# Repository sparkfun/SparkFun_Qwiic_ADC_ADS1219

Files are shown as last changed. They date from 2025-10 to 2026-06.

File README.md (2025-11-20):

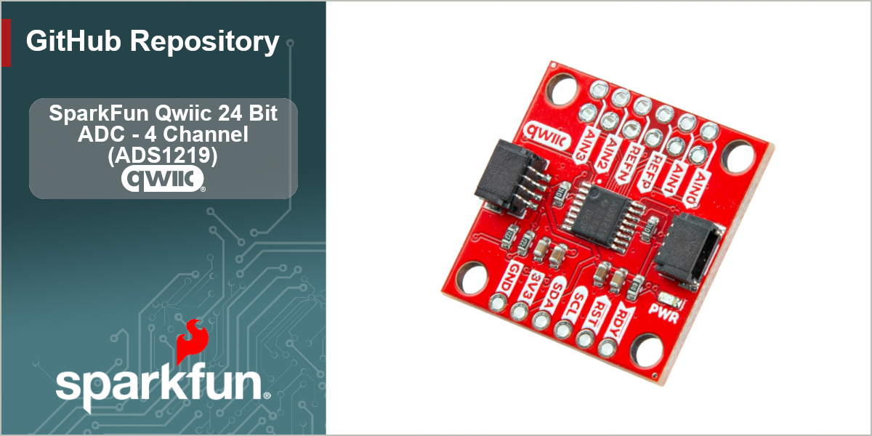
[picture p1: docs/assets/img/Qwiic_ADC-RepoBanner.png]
SparkFun Qwiic 24 Bit ADC - 4 Channel (ADS1219) (https://www.sparkfun.com/sparkfun-qwiic-24-bit-adc-4-channel-ads1219.html)


[*SparkFun Qwiic 24 Bit ADC - 4 Channel (ADS1219) (SEN-27544)*](https://www.sparkfun.com/sparkfun-qwiic-24-bit-adc-4-channel-ads1219.html)

A lot of the time you just need to add more analog inputs to solve a problem. It happens. The SparkFun Qwiic 24-Bit ADC can provide four channels of I2C controlled ADC input to your Qwiic enabled project. These channels can be used as single-ended inputs, or in pairs for differential inputs, running at sample rates of up to 1kHz. What makes this ADC even more powerful is that it has a programmable x1 or x4 gain amplifier that lets you "zoom in" on a very small change in analog voltage (but will still effect your input range and resolution). Utilizing our handy Qwiic system, it is easy to connect it to the rest of your system. However, we have broken out 0.1"-spaced pads too in case you prefer to use a breadboard. The analog inputs and reference pins are all broken out on 0.1"-spaced pads too. This board does not have screw terminals - there was not enough room!

The ADS1219 can use its own internal 2.048V voltage reference for measurements, or you can provide your own reference via the REFP and REFN breakout pads. You can also provide your own VDDA (AVDD) by opening the jumper and connecting a voltage to the VDDA pad. This ADC board has eight address jumpers that let you choose one of sixteen unique addresses (0x40 to 0x4F). With these, you can connect up to sixteen of these on the same I2C bus and have 64 channels of ADC. The maximum resolution of the converter is 24-bits, corresponding to 244.14nV per count at a gain of x1. At a gain of x4, the resolution is 61.04nV per count. Note: the effective resolution is limited to 20-bits.

Repository Contents
-------------------

* **/docs** - GitHub pages documentation files
* **/Documentation** - TI datasheet 
* **/Hardware** - KiCad design files (_pcb, _sch), Schematic (PDF)
* **/Production** - Production panel files (_pcb, gerbers)

Documentation
--------------
* [**Arduino Library**](https://github.com/sparkfun/SparkFun_ADS1219_Arduino_Library) - Arduino library for the ADS1219.
* [**Hookup Guide**](https://docs.sparkfun.com/SparkFun_Qwiic_ADC_ADS1219/)

Product Versions
-----------------

* [SPX-23455](https://www.sparkfun.com/sparkx-qwiic-24-bit-adc-4-channel-ads1219.html) - Original SparkX release.
* [SEN-27544](https://www.sparkfun.com/sparkfun-qwiic-24-bit-adc-4-channel-ads1219.html) - Initial SparkFun release.

License Information
-------------------

This product is _**open source**_! 

Please review the LICENSE.md file for license information. 

If you have any questions or concerns on licensing, please contact technical support on our [SparkFun forums](https://forum.sparkfun.com/viewforum.php?f=152).

Distributed as-is; no warranty is given.

- Your friends at SparkFun.

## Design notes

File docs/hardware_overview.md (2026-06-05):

Let's take closer look at the ADS1219 ADC and other hardware on this Qwiic breakout. Refer to the annotated image below as you read through.

<figure markdown>
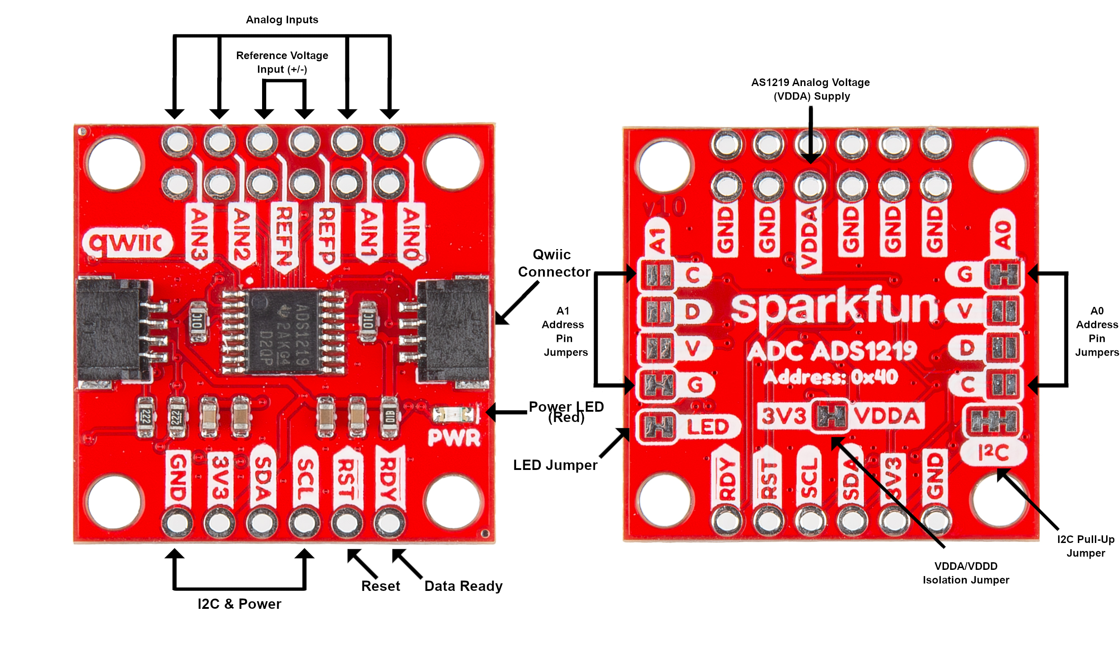
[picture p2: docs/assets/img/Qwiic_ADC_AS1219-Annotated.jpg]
Annotated photo of the Qwiic ADC - AS1219

</figure>

## ADS1219 Analog-to-Digital Converter

The ADS1219 is a high-precision, 24-bit analog-to-digital converter that communicates over I<sup>2</sup>C. It has two differential or four single-ended inputs managed by an internal input multiplexer, programmable gain settings of 1 or 4, rail-to-rail input buffers to allow connecting high-impedence devices directly to the ADS1219 and has 16 available I<sup>2</sup>C addresses so if you really need it, you can connect 16 of these to have up to 64 single-ended (or 32 differential) analog inputs on a single I<sup>2</sup>C bus! It also features an internal 2.048-V voltage reference and oscillator. Users can provide their own reference voltage throuh the REFN and REFP PTH pins on the board.

The ADS1219 has a supply voltage range of <b>2.3</b> to <b>5.5V</b>. The I<sup>2</sup>C address is configured via connecting the two address select pins (A0 and A1) to four pins on the ADS1219; Ground, DVDD, SDA and SCL. The board includes eight solder jumpers to set the ADS1219's address. Read on to the "Solder Jumpers" section on this page for information on adjusting the ADS1219's I<sup>2</sup>C address.

## Connectors

### Qwiic Connectors

As you'd expect, this breakout includes a pair of Qwiic connectors to easily integrate it into a Qwiic circuit. They connect to the ADS1219's I<sup>2</sup>C signals (SDA/SCL) and also power the ADC with <b>3.3V</b>.

### PTHs

The board breaks out all of the ADS1219's pins to three 0.1"-spaced PTH headers. On one side there is a 6-pin PTH header that routes the ADS1219's data and power pins including the I<sup>2</sup>C signals, reset and data ready pins. The other side of the board has a pair of 6-pin PTH headers. The outer header includes the ADS1219's four analog inputs as well as the positive and negative external reference voltage inputs. The inner header breaks out the ADS1219's analog voltage input (VDDA) along with five ground pins for the analog inputs and analog voltage input. Make sure to open the 3V3/VDDA solder jumper before connecting an external analog voltage input.

## LED

The sole LED on this board is a red power status LED to indicate when the board has power.

## Solder Jumpers

The board has eleven solder jumpers. The list below outlines the functionality of the three solder jumpers not related to setting the device's I<sup>2</sup>C address:

* <b>LED</b> - The LED jumper completes the red power LED circuit and is CLOSED by default. Open this jumper to disable the power LED.
* <b>I<sup>2</sup>C</b> - The I<sup>2</sup>C jumper pulls the SDA and SCL signals to <b>3.3V</b> through a pair of <b>2.2K&ohm;</b> resistors. Open the three-way jumper completely to remove the pull-ups from the bus if needed.
* <b>3V3-VDDA</b>  - The 3V3-VDDA jumper nets the ADS1219's digital and analog supply voltages together to both operate at <b>3.3V</b> and is CLOSED by default. Open this jumper to isolate the two voltages if you're supplying separate voltages for the analog and digital supplies.
 
The other eight jumpers control the ADS1219's I<sup>2</sup>C address and are grouped into labels <b>A1</b> and <b>A0</b>. Each group has solder jumpers labeled <b>G</b> (Ground), <b>V</b> (3.3V), <b>D</b> (SDA) and <b>C</b> (SCL). By default, the board connects both A1 and A0 to Ground and sets the address to <b>0x40</b>. The table below outlines all available configurations and the resulting addresses.

<table>
    <tr>
        <th>A1</th>
        <th>A0</th>
        <th>Address (Unshifted)</th>
    </tr>
        <td>G (GND)</td>
        <td>G (GND)</td>
        <td>0x40 (Default)</td>
    </tr>
    <tr>
        <td>G (GND)</td>
        <td>V (3.3V)</td>
        <td>0x41</td>
    </tr>
    <tr>
        <td>G (GND)</td>
        <td>D (SDA)</td>
        <td>0x42</td>
    </tr>
    <tr>
        <td>G (GND)</td>
        <td>C (SCL)</td>
        <td>0x43</td>
    </tr>
    <tr>
        <td>V (3.3V)</td>
        <td>G (GND)</td>
        <td>0x44</td>
    </tr>
    <tr>
        <td>V (3.3V)</td>
        <td>V (3.3V)</td>
        <td>0x45</td>
    </tr>
    <tr>
        <td>V (3.3V)</td>
        <td>D (SDA)</td>
        <td>0x46</td>
    </tr>
    <tr>
        <td>V (3.3V)</td>
        <td>C (SCL)</td>
        <td>0x47</td>
    </tr>
    <tr>
        <td>D (SDA)</td>
        <td>G (GND)</td>
        <td>0x48</td>
    </tr>
    <tr>
        <td>D (SDA)</td>
        <td>V (3.3V)</td>
        <td>0x49</td>
    </tr>
    <tr>
        <td>D (SDA)</td>
        <td>D (SDA)</td>
        <td>0x4A</td>
    </tr>
    <tr>
        <td>D (SDA)</td>
        <td>C (SCL)</td>
        <td>0x4B</td>
    </tr>
    <tr>
        <td>C (SCL)</td>
        <td>G (GND)</td>
        <td>0x4C</td>
    </tr>
    <tr>
        <td>C (SCL)</td>
        <td>V (3.3V)</td>
        <td>0x4D</td>
    </tr>
    <tr>
        <td>C (SCL)</td>
        <td>D (SDA)</td>
        <td>0x4E</td>
    </tr>
    <tr>
        <td>C (SCL)</td>
        <td>C (SCL)</td>
        <td>0x4F</td>
    </tr>
</table>

## Board Dimensions

The Qwiic ADC - ADS1219 is a standard 1"x1" Qwiic breakout with four mounting holes that fit a 4-40 screw.

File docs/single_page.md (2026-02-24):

---
hide:
  - navigation
  - toc
icon: fontawesome/solid/scroll
---

# Introduction
--8<-- "./docs/introduction.md"

# Quickstart Guide
--8<-- "./docs/quick_start.md"

# Hardware Overview
--8<-- "./docs/hardware_overview.md"

# Hardware Hookup
--8<-- "./docs/hardware_assembly.md"

# Arduino Setup
--8<-- "./docs/arduino_setup.md"

# Arduino Examples
--8<-- "./docs/arduino_examples.md"

# Troubleshooting
--8<-- "./docs/troubleshooting.md"

# Resources
--8<-- "./docs/resources.md"

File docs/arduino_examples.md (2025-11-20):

Let's take a look at a few of the examples included in the SparkFun ADS1219 Arduino Library.

## Example 01 - Single Shot

The first example shows how to take single-shot measurements of a differential input on channels A0 and A1. Open the example by navigating to **File** > **Examples** > **SparkFun ADS1219 Arduino Library** > **Example01_SingleShot**. Select your Board and Port and click the Upload button. After the code finishes uploading, open the [serial monitor](https://docs.arduino.cc/software/ide-v2/tutorials/ide-v2-serial-monitor/) with the baud set to **115200** and you should see some setup messages print out followed by readings in millivolts.

The example initializes the ADS1219 on the I<sup>2</sup>C bus with default settings and then attempts to take single-shot readings from the ADC. 

## Example 02 - Continuous

The second example shows how to take continuous measurements of a differential input on channels A0 and A1. This example is very similar to the previous one but instead of requesting for a single-shot synched readings, requests continuous readings every 10ms. Open the example from the SparkFun ADS1219 Arduino Library and upload it.

With the serial monitor open and set to **115200**, you should see an initialization message print followed by differential voltage readings from A0 and A1 in millivolts.

## Example 03 - Input Multiplexer

The third example shows how to configure the ADS1219's input multiplexer feature. This adjustable setting lets users set the ADS1219's input multiplexer to one of eight options using the `myADC.setInputMultiplexer();` function. Available settings are:

``` c++
  ADS1219_CONFIG_MUX_DIFF_P0_N1 //(Default)
  ADS1219_CONFIG_MUX_DIFF_P2_N3
  ADS1219_CONFIG_MUX_DIFF_P1_N2
  ADS1219_CONFIG_MUX_SINGLE_0
  ADS1219_CONFIG_MUX_SINGLE_1
  ADS1219_CONFIG_MUX_SINGLE_2
  ADS1219_CONFIG_MUX_SINGLE_3
  ADS1219_CONFIG_MUX_SHORTED
```

## Example 04 - Data Ready Interrupt

The fourth example demonstrates how to use the ADS1219's data ready pin to trigger an interrupt on a connected microcontroller. For this example, you'll need to connect the Data Ready (DRDY) pin to an [interrupt-capable I/O pin](https://docs.arduino.cc/language-reference/en/functions/external-interrupts/attachInterrupt/) on your development board. 

The code defaults to use D4 for the interrupt pin so if you need to switch to another pin, adjust this line:

``` c++
const int interruptPin = 4;
```

The example's setup sets the I<sup>2</sup>C clock speed to 400kHz for better performance and initializes the ADS1219 to read the voltage between AIN0 and Ground, adjusts the gain to x4 and configure the data rate to 1000 samples per second. Lastly, it configures the interrupt to go LOW when data is ready. The main loop just checks to see if the interrupt is seen, clears the flag and then prints readings in millivolts.

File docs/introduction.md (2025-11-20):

<figure markdown>
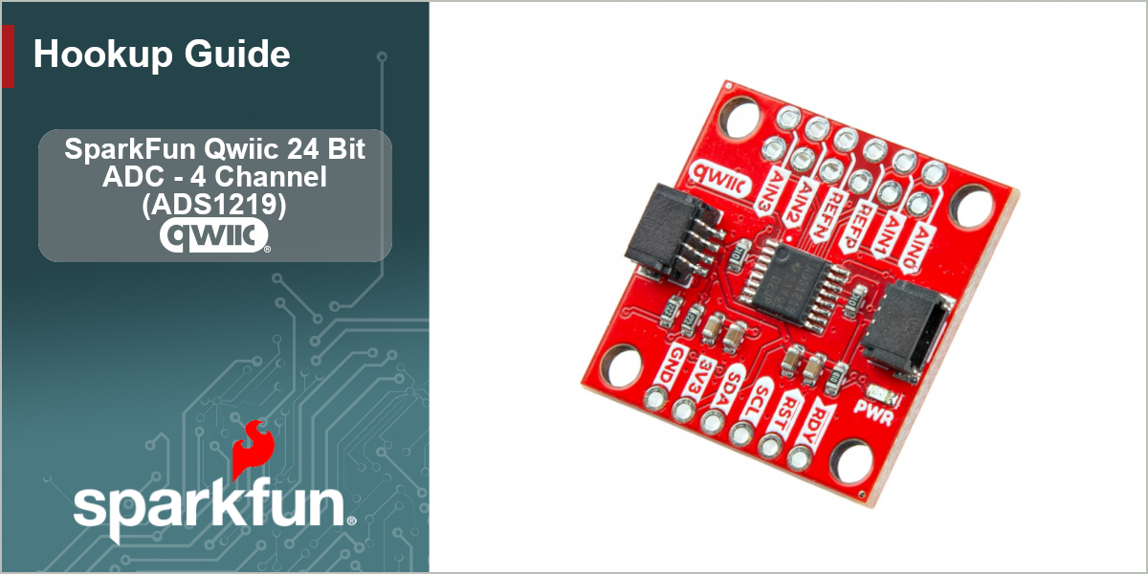
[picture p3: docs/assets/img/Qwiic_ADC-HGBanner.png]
Qwiic ADC Banner Image

</figure>

The [SparkFun Qwiic 24 Bit ADC - 4 Channel (ADS1219)](https://sparkle.sparkfun.com/sparkle/products/27544) is a simple Qwiic breakout board for the ADS1219 Analog-to-Digital converter. This breakout lets you add four channels of I<sup>2</sup>C controlled ADC input to your project. The ADS1219's channels can be used as single-ended inputs or in pairs for differential inputs and run at sample rates of up to 1kHz. The ADC also has a programmable gain amplifier (x1 or x4) to allow you to "zoom in" on very small changes in analog voltage (though this affects the input range and resolution). The ADS1219 has an internal 2.048V reference voltage but also allows for an external reference via the REFP/REFN PTH pads broken out on the board. This breakout naturally routes the power and I<sup>2</sup>C lines to a pair of Qwiic connectors for easy integration into a Qwiic circuit. Lastly, this breakout nets both of the ADS1219's supply voltages (analog/AVDD and digital/DVDD) to a single input but you can provide your own analog by opening the 3V3/VDDA jumper and connecting a voltage supply to the VDDA PTH pad. 

In this guide we'll cover everything you need to familiarize yourself with this Qwiic breakout, assemble it into a Qwiic circuit and how to use it with the SparkFun ADS1219 Arduino Library.

## Required Materials

In order to use this Qwiic breakout board, you'll need the following materials:

* [SparkFun RedBoard IoT - ESP32](https://www.sparkfun.com/sparkfun-iot-redboard-esp32-development-board.html) (or other Arduino development board)
* [Qwiic Cable](https://www.sparkfun.com/flexible-qwiic-cable-100mm.html)
* An analog input such as a flex sensor, force-sensitive resistor or load cell. You can find all types of each of these sensors in our [Flex/Force Category](https://www.sparkfun.com/sensors/flex.html).

### Quick Start Materials

If you'd like to build the demo circuit in the Quick Start guide you'll need the following extra items:

* [Flex Sensor 2.2"](https://www.sparkfun.com/flex-sensor-2-2.html)
* [10k&ohm; Resistor Pack (100)](https://www.sparkfun.com/resistor-10k-ohm-1-4-watt-pth-20-pack-thick-leads.html)
* [M/F Jumper Wires](https://www.sparkfun.com/jumper-wires-premium-6-m-f-pack-of-10.html)
* [Breadboard](https://www.sparkfun.com/development-boards/prototyping-boards/breadboard.html)

## Topics Covered

This guide contains three main sections: **Quickstart Guide**, **Hardware** and **Software**. 

The Quickstart Guide goes over a simple demo circuit for the Qwiic ADC - AS1219 using a flex sensor to read voltage changes using the SparkFun ADS1219 Arduino Library. This section assumes a working knowledge of how to use a development board with Arduino, through-hole soldering and building prototype circuits using a breadboard.

The Hardware section provides a detailed overview of the ADS1219 and other hardware present on the Qwiic 24 Bit ADC as well as instructions on assembling it into a Qwiic circuit.

The Software section covers how to install the SparkFun AS1219 Arduino Library along with brief overviews of some of the examples included in the library.

## Resources and Support Documentation

You'll find the board design files (KiCad files & schematic), relevant documentation (datasheets, white papers, etc.) and other helpful links in the **Resources**. Lastly, the **Support** section includes a Troubleshooting page that includes any helpful tips specific to this board as well as information on how to receive technical support from SparkFun.

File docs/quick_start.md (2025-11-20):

In this Quick Start guide we'll go over how to assemble the SparkFun Qwiic 24 Bit ADC - 4 Channel (ADS1219) in a Qwiic circuit to measure the output voltage of a flex sensor assembled to function as a voltage divider. 

This guide assumes users have a basic understanding of using Qwiic breakout and development boards, through-hole soldering, breadboard prototyping as well as how to use the Arduino IDE. If you're not familiar with all of these concepts, read on through the rest of this Hookup Guide for detailed information on how to use this breakout board with the Arduino IDE.

## Flex Sensor Demo Assembly

Since we're doing some prototype testing with this board, we opted to solder male headers to the Qwiic ADC - AS1219's PTH pads to easily connect jumper wires to the board.

Connect the flex sensor to the Qwiic ADC - AS1219 with the following steps:

* Plug the flex sensor into the breadboard.
* Connect one leg of a 10k&ohm; resistor to one of the flex sensor's pins and the other to a free row on the breadboard.
* Take one jumper wire (white wire in the photo below) and connect AIN0 on the Qwiic ADC to same row on the breadboard as the Flex Sensor pin connected to the 10k&ohm; resistor.
* Next, use a second jumper wire (red wire in the photo below) to connect the flex sensor's other pin to the Qwiic ADC's VDDA pin (this label is on the bottom of the board).
* Now use the third jumper wire (black wire in the photo below) and connect the other or "free" end of the 10k&ohm; resistor to one of the ground pins on the Qwiic ADC.

Your circuit should look similar to the photo below:

<figure markdown>
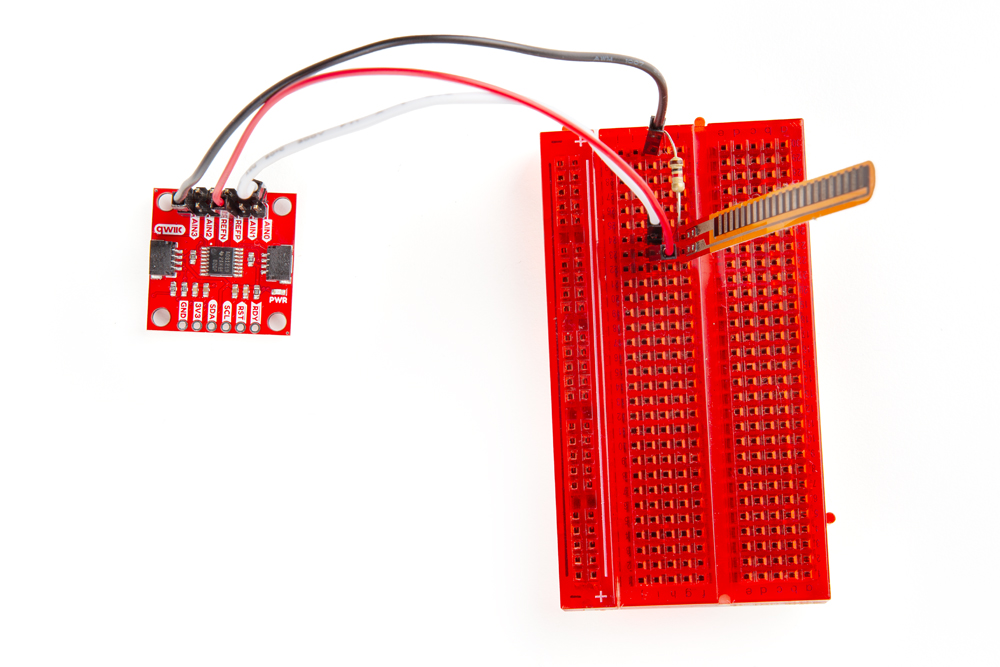
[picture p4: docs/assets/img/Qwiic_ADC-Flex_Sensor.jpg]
Photo showing flex sensor connected to the Qwiic ADC - AS1219

</figure>

Now that we've finished assembling our flex sensor circuit, it's time to connect the Qwiic ADC - AS1219 to our RedBoard IoT - ESP32. Simply connect the two together with a Qwiic cable plugged into the Qwiic connectors:

<figure markdown>
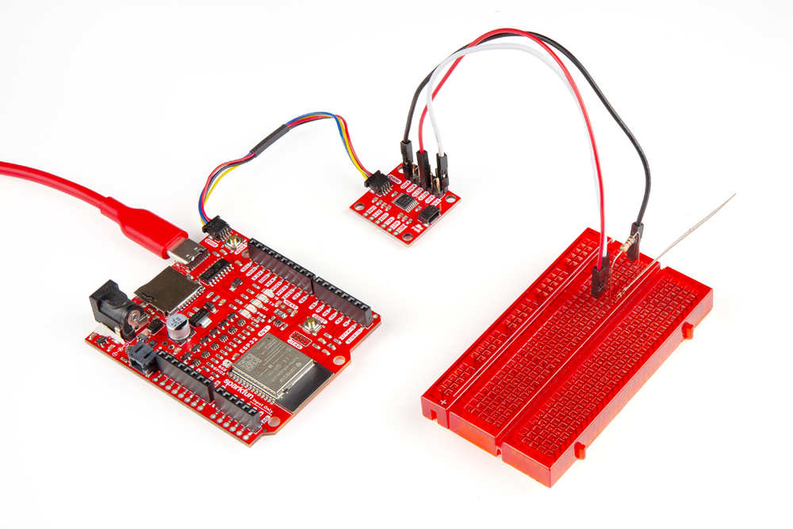
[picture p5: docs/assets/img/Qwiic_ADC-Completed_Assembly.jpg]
Photo showing completed flex sensor demo circuit

</figure>

## Arduino Example

For this example, we'll be using a slightly modified version of Example 01 - Single Shot from the [SparkFun AS1219 Arduino Library](https://github.com/sparkfun/SparkFun_ADS1219_Arduino_Library).

* Open the [Arduino IDE](https://docs.arduino.cc/software/ide-v2/tutorials/getting-started-ide-v2/).
* Open the [Library Manager](https://docs.arduino.cc/software/ide-v2/tutorials/ide-v2-installing-a-library/) tool, search for "SparkFun AS1219" and install the latest version. This library was built using the [SparkFun Toolkit](https://github.com/sparkfun/SparkFun_Toolkit) so if you have not already installed it, search for "SparkFun Toolkit" in the Library Manager to install the dependency. 
* Open "Example 01 - Single Shot".
* Add the following code to the <code>void setup()</code> below this line: <code>Serial.println("ADC initialized");</code>:
``` c++
  myADC setInputMultiplexer(ADS1219_CONFIG_MUX_SINGLE_0);

  Serial println("Reading from A0");
```
* Select your Board (SparkFun RedBoard IoT - ESP32 or other board) and Port and click "Upload".
* After the code compiles and finishes uploading, open the [serial monitor](https://docs.arduino.cc/software/ide-v2/tutorials/ide-v2-serial-monitor/) with the baud set to **115200**.
* Now, gently bend the flex sensor and you should see the voltage readings move down like the screenshot below. Continue flexing the sensor and it should drop further or release it and the voltages should jump back up.

<figure markdown>
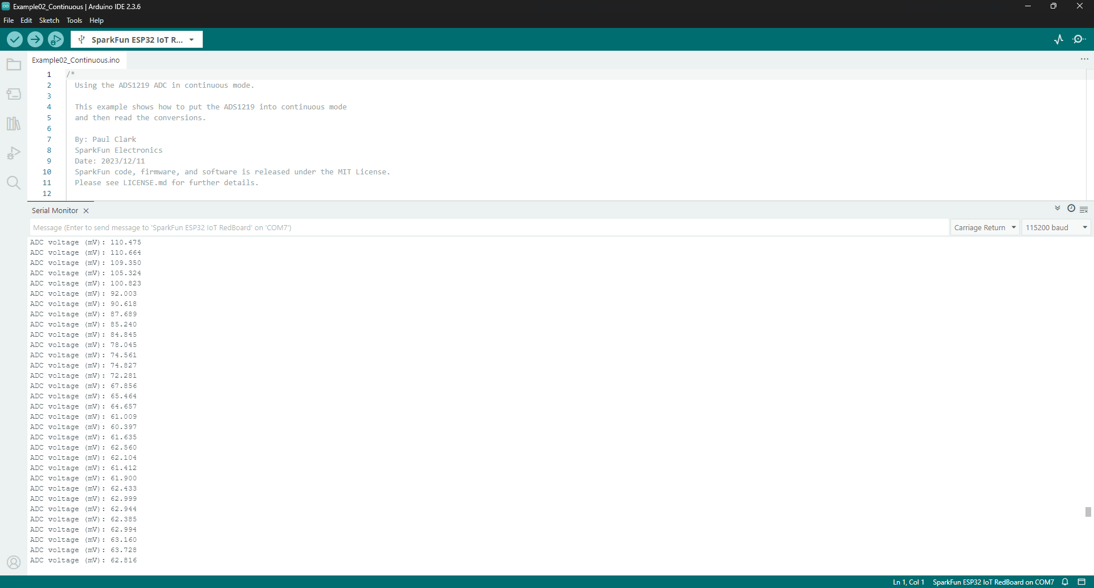
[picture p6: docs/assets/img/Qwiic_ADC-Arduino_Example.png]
Screenshot of serial monitor output in Arduino

</figure>

**Code to Note**

The Single Shot example defaults to measure a differential input from the A0 and A1 channels so in the instructions above we modified the code to configure the ADS1219 to just read a single input on A0 using the <code>setInputMultiplexer()</code> function and then perform a serial print informing of the change:
``` c++
  myADC setInputMultiplexer(ADS1219_CONFIG_MUX_SINGLE_0);

  Serial println("Reading from A0");
```

The main loop of this example attempts to start a single-shot conversion and waits for it to complete every 10ms:

``` c++
  if (myADC.startSync()) // Start a single-shot conversion. This will return true on success.
  {
    while (myADC.dataReady() == false) // Check if the conversion is complete. This will return true if data is ready.
    {
      delay(10); // The conversion is not complete. Wait a little to avoid pounding the I2C bus.
    }    
```

If that single-shot conversion completes, we read the result, convert it to millivolts and print out that value with three decimal points. If it fails, it prints out a failure message and waits one second before attempting again:

``` c++
    myADC.readConversion(); // Read the conversion result from the ADC. Store it internally.
    float milliVolts = myADC.getConversionMillivolts(); // Convert to millivolts.
    Serial.print("ADC voltage (mV): ");
    Serial.println(milliVolts, 3); // Print milliVolts with 3 decimal places
  }
  else
  {
    Serial.println("ADC start conversion failed. Please check your wiring! Retrying...");
    delay(1000);
  }
```

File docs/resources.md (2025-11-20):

For more information on the SparkFun Qwiic 24 Bit ADC - 4 Channel (ADS1219), check out the following resources:

* [Schematic](./assets/board_files/Qwiic_ADC_ADS1219.pdf)
* [KiCad Files](./assets/board_files/Qwiic_ADC_ADS1219.zip)
* [Datasheet](./assets/component_documentation/ads1219.pdf) (ADS1219)
* [SparkFun ADS1219 Arduino Library](https://github.com/sparkfun/SparkFun_ADS1219_Arduino_Library)
* [GitHub Repository](https://github.com/sparkfun/SparkFun_Qwiic_ADC_ADS1219)

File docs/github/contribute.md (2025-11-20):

# Contribute: Make an Augmentation!
Spot an improvement opportunity? Feel free to contribute to our open-source design and documentation. 

## :material-file-document-multiple:&nbsp;Improve our Documentation
All of this documentation can be modified by you! Please help us make it better.

* These pages are contained in the [`docs` folder](https://github.com/sparkfun/SparkFun_Qwiic_ADC_ADS1219/tree/main/docs) of the [SparkFun Ambient Light Sensor - VEML7700 repository](https://github.com/sparkfun/SparkFun_Qwiic_ADC_ADS1219).

<!-- ### :material-source-pull:&nbsp;Submit a Correction -->
### Submit a Correction

1. With a GitHub account, [fork this repository](https://github.com/sparkfun/SparkFun_Qwiic_ADC_ADS1219/fork).
2. Add your corrections or improvements to the markdown file.
3. File a pull request with your changes, and enjoy making the ~~words~~ ~~worlds~~ world a better place.
	* Once received, the documentation specialist will automatically be notified.
	* We will review your suggested improvements to make sure they are correct and fit within our documentation standards.

## :material-cog:&nbsp;Improve our Hardware Design
All of our designs are open-source! Please help us make it better.

* Our board design files are contained in the [`Hardware` folder](https://github.com/sparkfun/SparkFun_Qwiic_ADC_ADS1219/tree/main/Hardware) of the [SparkFun Ambient Light Sensor - VEML7700 repository](https://github.com/sparkfun/SparkFun_Qwiic_ADC_ADS1219).

<!-- ### :material-source-pull:&nbsp;Submit a Design Enhancement -->
### Submit a Design Enhancement

1. With a GitHub account, [fork this repository](https://github.com/sparkfun/SparkFun_Qwiic_ADC_ADS1219/fork).
2. Add your design augmentation(s)
3. File a pull request with your changes, and enjoy making the ~~words~~ ~~worlds~~ world a better place.
	1. Once received, the engineer in charge of the original design will automatically be notified.
	2. We will review your suggested improvement(s) to verify that they are within our board design standards and meet our product design requirements.
	3. If approved, we will flag these changes for our next board revision. Congrats! 🍻

		!!! info
			Even if your suggestion is accepted, these changes may not be immediately available for purchase. We may have to cycle through our current product inventory first.

## Contributors&nbsp;:clap:
Let's provide some recognition to the contributors for this project!

GitHub Contributors Image
<br>


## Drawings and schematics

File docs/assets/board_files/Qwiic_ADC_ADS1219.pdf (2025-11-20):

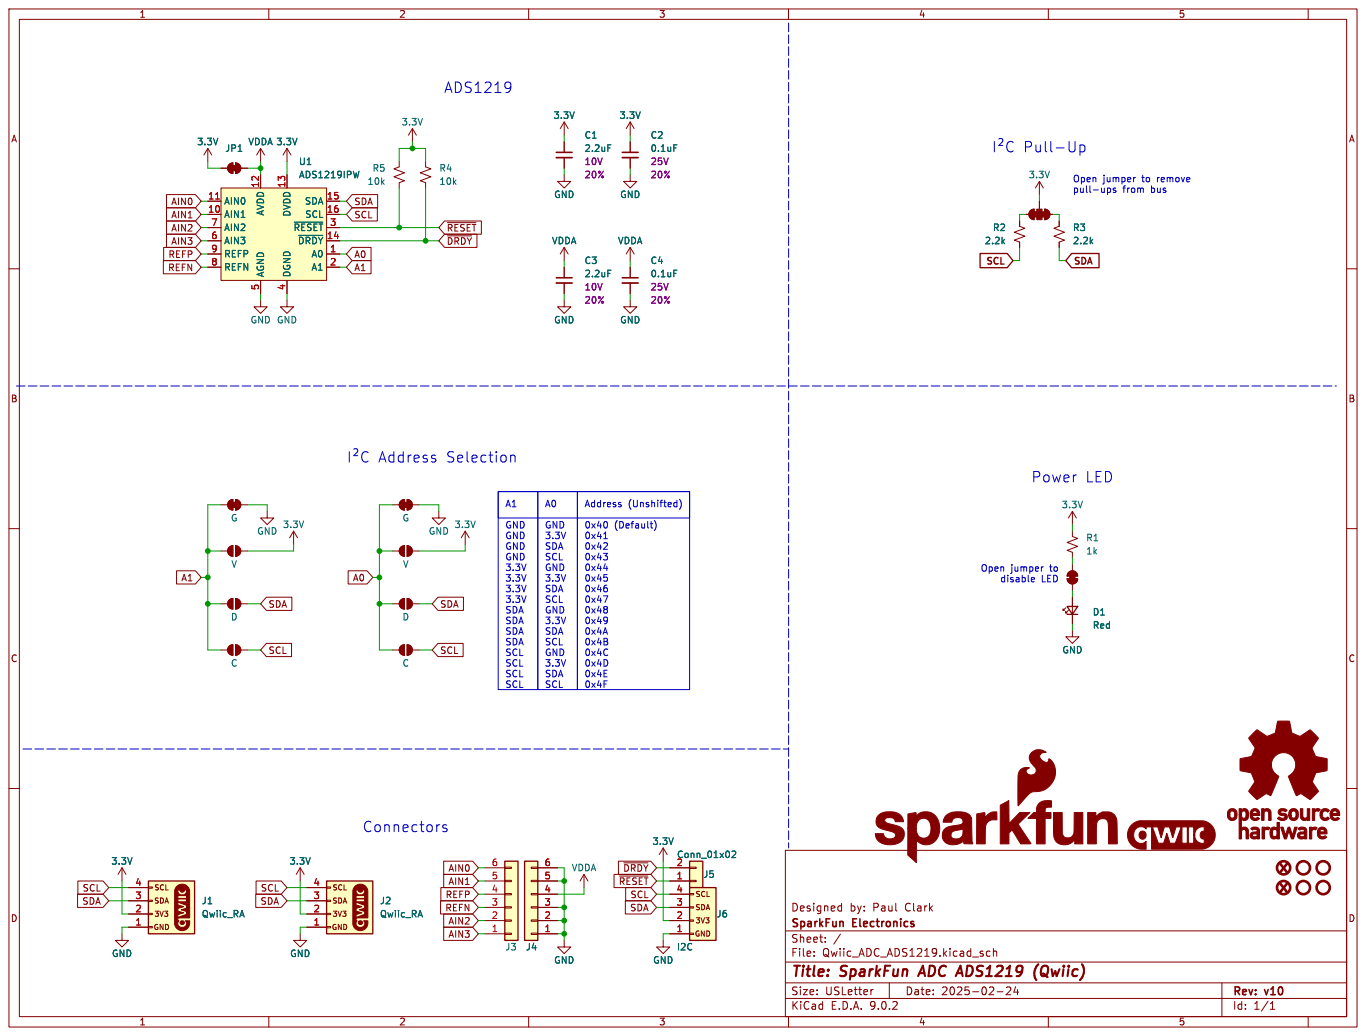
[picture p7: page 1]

4 SDA 15 SCL 16 ~{RESET}3 ~{DRDY} 14 A0 1 A1 2 U1ADS1219IPW
10k GND

Open jumper to remove

4 SDA 15 SCL 16 ~{RESET}3 ~{DRDY} 14 A0 1 A1 2

SCL þÿI²CAddress Selection

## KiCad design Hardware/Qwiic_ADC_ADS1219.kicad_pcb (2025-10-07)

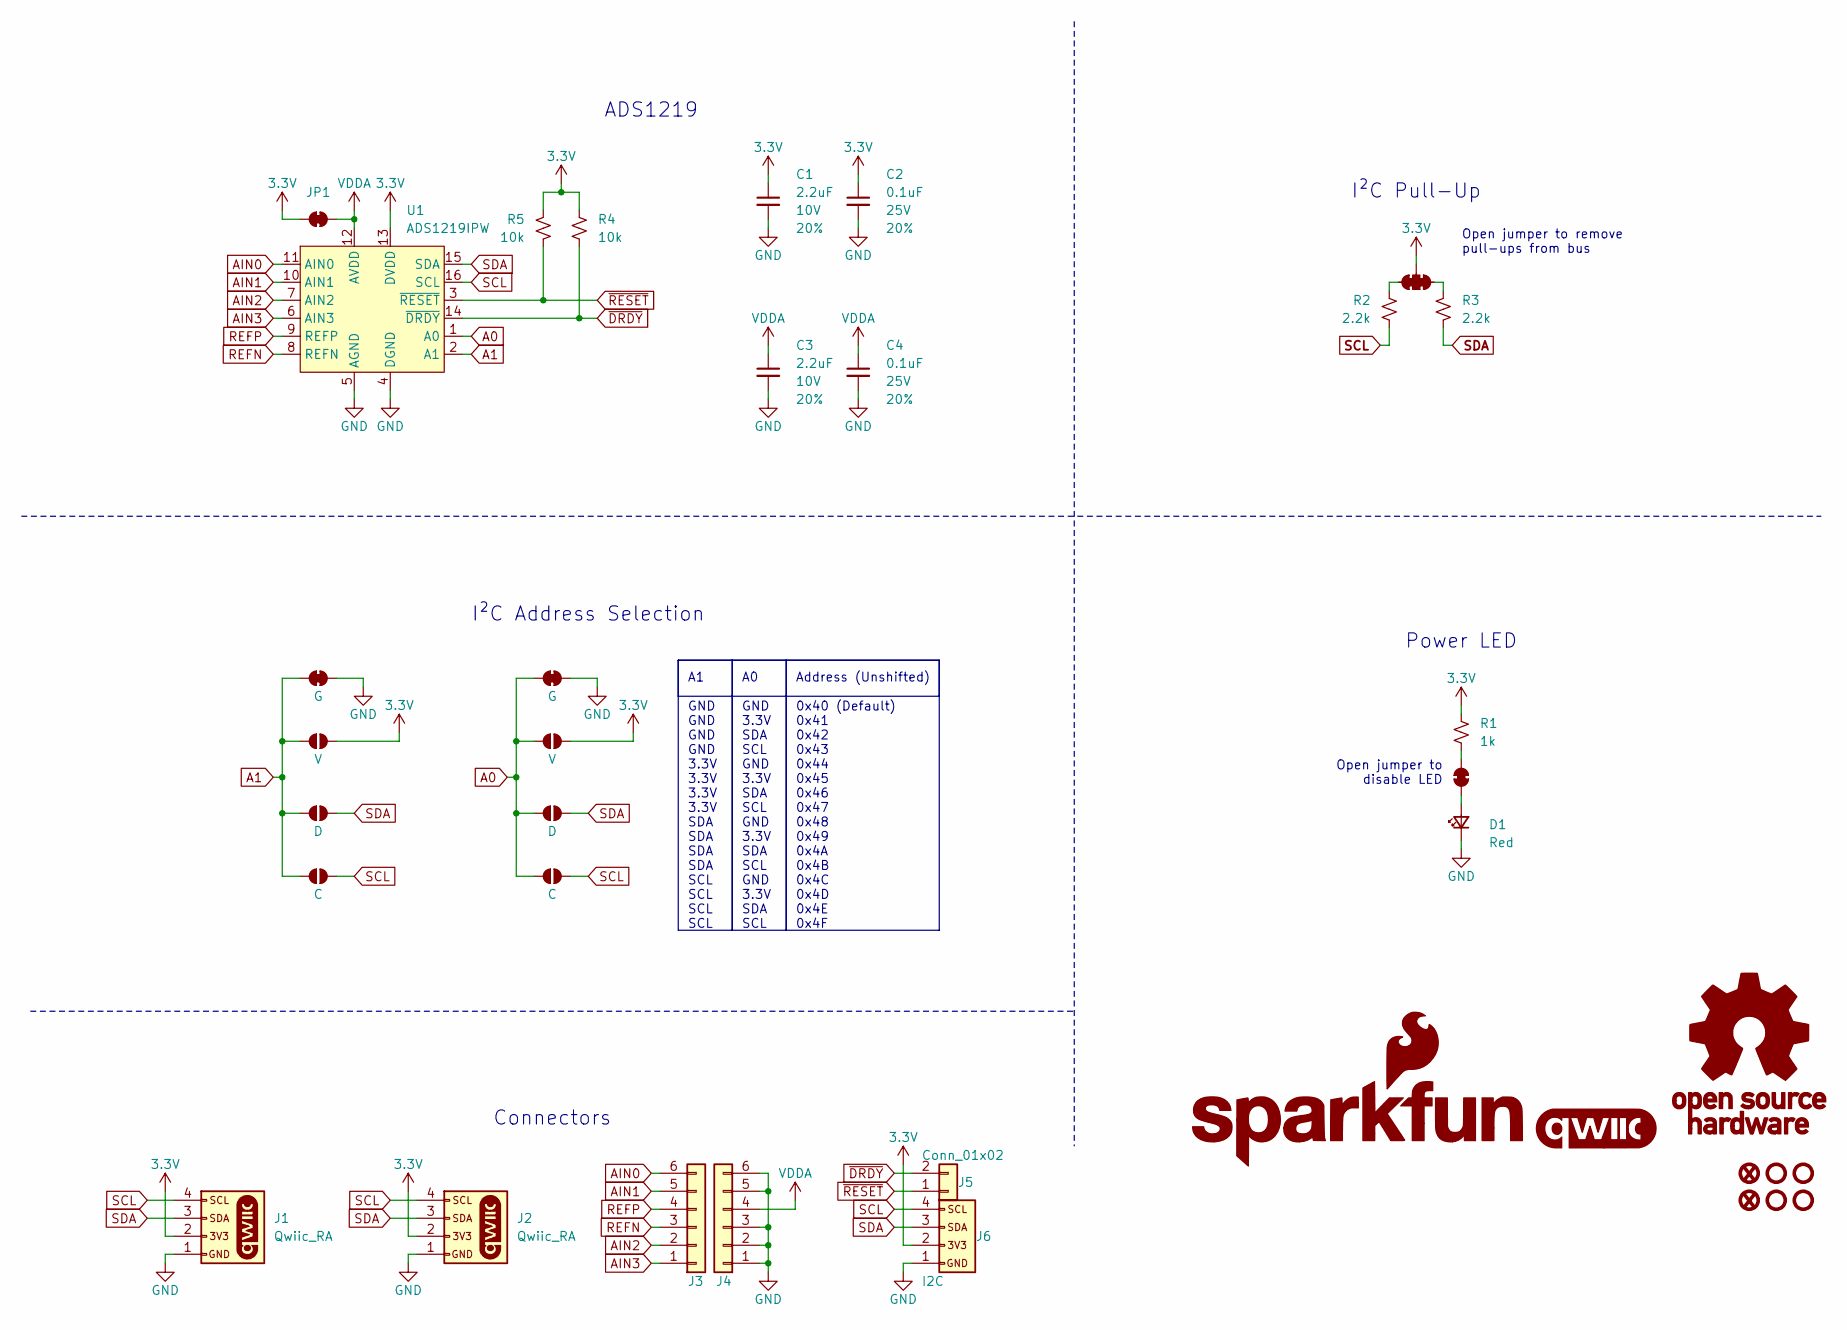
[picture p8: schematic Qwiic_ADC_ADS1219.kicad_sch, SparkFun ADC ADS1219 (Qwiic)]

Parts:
C1, C3: 2.2uF; C_0603_1608Metric; Voltage 10V; Tolerance 20%
C2, C4: 0.1uF; C_0603_1608Metric; Voltage 25V; Tolerance 20%
D1: Red; LED_0603_1608Metric_Red
FID1, FID3: Fiducial_0.5mm; Fiducial_0.5mm_Mask1mm
G1: SparkFun_Logo
J1, J2: Qwiic_RA; JST_SMD_1.0mm-4_Black
J3, J4: Conn_01x06; 1x06
J5: Conn_01x02; 1x02
J6: I2C; 1x04
JP1, JP2: Jumper_2_NC_Trace
JP3: Jumper_3_NC-2_Trace
JP4, JP8: G; Jumper_2_NC_Trace
JP5, JP9: V; Jumper_2_NO
JP6, JP10: D; Jumper_2_NO
JP7, JP11: C; Jumper_2_NO
R1: 1k; R_0603_1608Metric
R2, R3: 2.2k; R_0603_1608Metric
R4, R5: 10k; R_0603_1608Metric
ST1, ST2, ST3, ST4: Standoff
U1: ADS1219IPW; TSSOP-16

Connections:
3.3V: C1.1, C2.1, J1.2, J2.2, J6.2, JP1.1 (A), JP3.2 (B), JP5.2 (B), JP9.2 (B), R1.2, R4.2, R5.1, U1.13 (DVDD)
A0: JP4.1 (A), JP5.1 (A), JP6.1 (A), JP7.1 (A), U1.1 (A0)
A1: JP8.1 (A), JP9.1 (A), JP10.1 (A), JP11.1 (A), U1.2 (A1)
AIN0: J3.6, U1.11 (AIN0)
AIN1: J3.5, U1.10 (AIN1)
AIN2: J3.2, U1.7 (AIN2)
AIN3: J3.1, U1.6 (AIN3)
GND: C1.2, C2.2, C3.2, C4.2, D1.1 (K), J1.1, J2.1, J4.1, J4.2, J4.3, J4.5, J4.6, J6.1, JP4.2 (B), JP8.2 (B), U1.4 (DGND), U1.5 (AGND)
unnamed: D1.2 (A), JP2.1 (A)
unnamed: JP2.2 (B), R1.1
unnamed: JP3.1 (A), R3.1
unnamed: JP3.3 (C), R2.2
REFN: J3.3, U1.8 (REFN)
REFP: J3.4, U1.9 (REFP)
SCL: J1.4, J2.4, J6.4, JP7.2 (B), JP11.2 (B), R2.1, U1.16 (SCL)
SDA: J1.3, J2.3, J6.3, JP6.2 (B), JP10.2 (B), R3.2, U1.15 (SDA)
VDDA: C3.1, C4.1, J4.4, JP1.2 (B), U1.12 (AVDD)
~DRDY: J5.2, R4.1, U1.14 (~DRDY)
~RESET: J5.1, R5.2, U1.3 (~RESET)

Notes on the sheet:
Open jumper to remove pull-ups from bus
Connectors
Power LED
I²C Address Selection
Open jumper to disable LED
A1 GND GND GND GND 3.3V 3.3V 3.3V 3.3V SDA SDA SDA SDA SCL SCL SCL SCL
Address (Unshifted) 0x40 (Default) 0x41 0x42 0x43 0x44 0x45 0x46 0x47 0x48 0x49 0x4A 0x4B 0x4C 0x4D 0x4E 0x4F
ADS1219
I²C Pull-Up
A0 GND 3.3V SDA SCL GND 3.3V SDA SCL GND 3.3V SDA SCL GND 3.3V SDA SCL

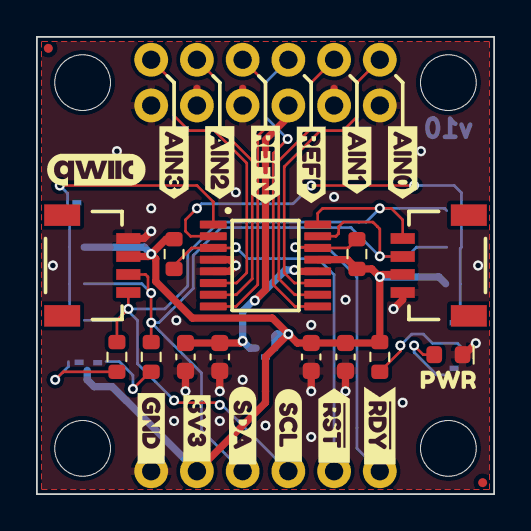
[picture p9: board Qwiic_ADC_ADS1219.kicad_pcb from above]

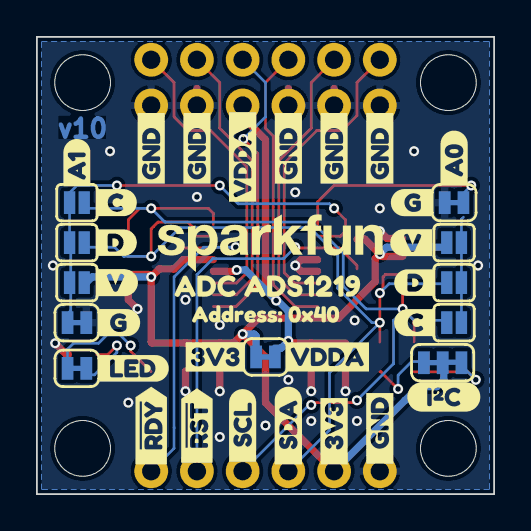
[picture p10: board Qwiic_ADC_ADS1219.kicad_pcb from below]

Board: 2 copper layers, 25.4 x 25.4 mm, 75 parts (39 on the bottom side), 19 nets.

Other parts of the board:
kibuzzard-64C3B30F: G***; kibuzzard-64C3B30F
kibuzzard-64C3BD7A: G***; kibuzzard-64C3BD7A
kibuzzard-64C36D1A: G***; kibuzzard-64C36D1A
kibuzzard-64C36D2D: G***; kibuzzard-64C36D2D
kibuzzard-64C36D5B: G***; kibuzzard-64C36D5B
kibuzzard-64C36D6C: G***; kibuzzard-64C36D6C
kibuzzard-64C36D47: G***; kibuzzard-64C36D47
kibuzzard-64C36D91: G***; kibuzzard-64C36D91
kibuzzard-64C37A88: G***; kibuzzard-64C37A88
kibuzzard-64C37CC9: G***; kibuzzard-64C37CC9
kibuzzard-64C38090: G***; kibuzzard-64C38090
kibuzzard-67BCC03F: G***; kibuzzard-67BCC03F
kibuzzard-67BCE7E0: G***; kibuzzard-67BCE7E0
kibuzzard-67BCE9A5: G***; kibuzzard-67BCE9A5
kibuzzard-67BCE9C9: G***; kibuzzard-67BCE9C9
kibuzzard-67BCE9CD: G***; kibuzzard-67BCE9CD
kibuzzard-67BCE9E1: G***; kibuzzard-67BCE9E1
kibuzzard-67BCE80E: G***; kibuzzard-67BCE80E
kibuzzard-67BCE89D: G***; kibuzzard-67BCE89D
kibuzzard-67BCE805: G***; kibuzzard-67BCE805
kibuzzard-67BCE809: G***; kibuzzard-67BCE809
kibuzzard-67BCE889: G***; kibuzzard-67BCE889
kibuzzard-67BCE896: G***; kibuzzard-67BCE896
kibuzzard-67BCE899: G***; kibuzzard-67BCE899
kibuzzard-67BCEA1E: G***; kibuzzard-67BCEA1E
kibuzzard-67BCEA3A: G***; kibuzzard-67BCEA3A
kibuzzard-67BCEA31: G***; kibuzzard-67BCEA31
kibuzzard-67BCEA48: G***; kibuzzard-67BCEA48
kibuzzard-67BCEA55: G***; kibuzzard-67BCEA55
kibuzzard-67BCEA65: G***; kibuzzard-67BCEA65
kibuzzard-67BCEA70: G***; kibuzzard-67BCEA70
kibuzzard-67BCEAAB: G***; kibuzzard-67BCEAAB
kibuzzard-67BCEAC6, kibuzzard-67BCEAC6#2, kibuzzard-67BCEAC6#3, kibuzzard-67BCEAC6#4, kibuzzard-67BCEAC6#5: G***; kibuzzard-67BCEAC6
kibuzzard-67BCEAE1: G***; kibuzzard-67BCEAE1
kibuzzard-67BCEB1D: G***; kibuzzard-67BCEB1D
kibuzzard-67BCEB15: G***; kibuzzard-67BCEB15
kibuzzard-67BCEB32: G***; kibuzzard-67BCEB32

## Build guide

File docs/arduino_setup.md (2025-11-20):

!!! arduino
    This example assumes you are using the latest version of the Arduino IDE on your desktop. If this is your first time using Arduino IDE, library, or board add-on, please review the following tutorials.

    - [Installing the Arduino IDE](https://learn.sparkfun.com/tutorials/installing-arduino-ide)
    - [Installing an Arduino Library](https://learn.sparkfun.com/tutorials/installing-an-arduino-library)
    - [Installing Board Definitions in the Arduino IDE](https://learn.sparkfun.com/tutorials/installing-board-definitions-in-the-arduino-ide)

    ## Installing the SparkFun ADS1219 Arduino Library

!!! note "SparkFun Toolkit"

    This library is built using the [SparkFun Toolkit](https://github.com/sparkfun/SparkFun_Toolkit) so you'll need to make sure that is installed before using this library. Install the SparkFun Toolkit with the Arduino Library manager by searching "SparkFun Toolkit" and installing the latest version. Users who prefer manually installing Arduino Libraries can download it from the [GitHub Repository](https://github.com/sparkfun/SparkFun_Toolkit).

## SparkFun ADS1219 Arduino Library

The SparkFun ADS1219 Arduino Library lets users easily get started with the ADS1219 with basic commands and six examples. Install the library using the Arduino Library Manager tool by searching for "SparkFun ADS1219" and install the latest version. If you'd prefer to manually install the library, you can download it from the [GitHub Repository](https://github.com/sparkfun/SparkFun_ADS1219_Arduino_Library) or you can download a ZIP of the repository [here](https://github.com/sparkfun/SparkFun_ADS1219_Arduino_Library/archive/refs/heads/main.zip).

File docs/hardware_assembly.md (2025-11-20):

## Qwiic Assembly

Since this is a Qwiic board, assembling it into a circuit is easy. Just connect the Qwiic ADC to a Qwiic-enabled development board using a Qwiic connector. From there, you'll obviously need some analog inputs to convert so for a quick demo we've set up a simple circuit to measure output from a flex sensor. Head back to the [Quick Start Guide](./quick_start.md) for instructions on how to set up the flex sensor demo circuit.

<figure markdown>
Photo showing completed flex sensor demo circuit.
</figure>

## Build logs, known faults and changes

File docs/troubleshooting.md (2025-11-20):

## General Troubleshooting

!!! note
    <span class="glyphicon glyphicon-question-sign" aria-hidden="true"></span>
        <strong> Not working as expected and need help? </strong> <br /><br />

    If you need technical assistance and more information on a product that is not working as you expected, we recommend heading on over to the <a href="https://www.sparkfun.com/technical_assistance">SparkFun Technical Assistance</a> page for some initial troubleshooting. <br /><br />

    <div style="text-align: center"><a href="https://www.sparkfun.com/technical_assistance" target="sfe_technical_assistance" class="md-button">SparkFun Technical Assistance Page</a></div>

    If you don't find what you need there, the <a href="https://community.sparkfun.com/">SparkFun Forums</a> are a great place to find and ask for help. If this is your first visit, you'll need to create a forum account to search product forums and post questions.<br /><br />

    <div style="text-align: center"><a href="https://community.sparkfun.com/" class="md-button md-button--primary">Log Into SparkFun Forums</a></div>

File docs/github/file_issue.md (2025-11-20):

# Did we make a mistake?

Spot something wrong? Please let us know. 

## Discrepancies in the Documentation

All of our documentation can be modified by you! Please help us make it better.

* The documentation files for these pages are contained in the [`docs` folder](https://github.com/sparkfun/SparkFun_Qwiic_ADC_ADS1219/tree/main/docs) of the [SparkFun Qwiic ADC - AS1219](https://github.com/sparkfun/SparkFun_Qwiic_ADC_ADS1219).

### 🔍 Spot something wrong?

If a section of the documentation is incorrect, please [open an issue](https://github.com/sparkfun/SparkFun_Qwiic_ADC_ADS1219/issues) and let us know.

### Do you have a suggested correction?

1. With a GitHub account, [fork this repository](https://github.com/sparkfun/SparkFun_Qwiic_ADC_ADS1219/fork).
2. Add your correction(s) or improvement(s) to the markdown file(s)
3. File a pull request with your changes, and enjoy making the ~~words~~ ~~worlds~~ world a better place.
	* Once received, the documentation specialist will automatically be notified.
	* We will review your suggested improvement(s) to make sure they are correct and fit within our documentation standards.

## Problems in the Hardware Design

All of our designs are open-source! Please help us make it better.

* Our board design files are contained in the [`Hardware` folder](https://github.com/sparkfun/SparkFun_Qwiic_ADC_ADS1219/tree/main/Hardware) of the [SparkFun Qwiic ADC - AS1219](https://github.com/sparkfun/SparkFun_Qwiic_ADC_ADS1219).

### Does something not make sense? 🤔

If part of the design is confusing, please [open an issue](https://github.com/sparkfun/SparkFun_Qwiic_ADC_ADS1219/issues) and let us know.

### Did we forget to include an important function of the board? 🤦

If part of the board's functionality is missing, please [open an issue](https://github.com/sparkfun/SparkFun_Qwiic_ADC_ADS1219/issues) and file a feature request.

!!! tip "Design Considerations"
	Please keep in mind that we may intentionally exclude certain functions of the board to meet our product design requirements.
	
	* *For example, our Qwiic Micro boards are intended to fit on a small board layout and only use I<sup>2</sup>C communication; therefore, we may not have the SPI and interrupt pins available for users.*

### Do you wish to contribute directly to improving the board design?

1. With a GitHub account, [fork this repository](https://github.com/sparkfun/SparkFun_Qwiic_ADC_ADS1219/fork).
2. Add your design augmentation(s)
3. File a pull request with your changes, and enjoy making the ~~words~~ ~~worlds~~ world a better place.
	1. Once received, the engineer in charge of the original design will automatically be notified.
	2. We will review your suggested improvement(s) to verify that they are within our board design standards and meet our product design requirements.
	3. If approved, we will flag these changes for our next board revision. Congrats! 🍻

		!!! info
			Even if your suggestion is accepted, these changes may not be immediately available for purchase. We may have to cycle through our current product inventory first.

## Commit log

2024-11-20 Transition to reds
    - Change PCB color to Red
    - Add "V10" stamp to B.Cu
    - Change SparkX Logo to SparkFun
    - No outstanding bugs in SPX repo, no circuit changes made
    - Generate new panel
    [Qwiic_ADC_ADS1219.kicad_pcb, Qwiic_ADC_ADS1219.kicad_sch]
2025-02-24 Update silk. Change address jumper names.
    [Qwiic_ADC_ADS1219.kicad_pcb, Qwiic_ADC_ADS1219.kicad_sch]
2025-10-07 Changes board setup to two layers and adds measures
    [Qwiic_ADC_ADS1219.kicad_pcb]
